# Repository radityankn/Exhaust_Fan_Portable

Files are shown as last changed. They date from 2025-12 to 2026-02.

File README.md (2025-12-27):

| Supported Targets | ESP32 | ESP32-C2 | ESP32-C3 | ESP32-C5 | ESP32-C6 | ESP32-C61 | ESP32-H2 | ESP32-P4 | ESP32-S2 | ESP32-S3 |
| --- | ----- | --- | --- | --- | --- | --- | --- | --- | --- | --- |

# _LEDC Basic Example_

(See the README.md file in the upper level 'examples' directory for more information about examples.)

This example shows how to use the LEDC to generate a PWM signal using the `LOW SPEED` mode.
To use `HIGH SPEED` mode check if the selected SoC supports this mode.

## How to use example

### Hardware Required

* A development board with any Espressif SoC (e.g., ESP32-DevKitC, ESP-WROVER-KIT, etc.)
* A USB cable for power supply and programming

Connect the GPIO to an oscilloscope to see the generated signal:

|ledc channel| GPIO  |
|:---:|:-----:|
| Channel 0  | GPIO5 |

### Configure the project

The example uses fixed PWM frequency of 4 kHz, duty cycle in 50%, and output GPIO pin. To change them, adjust `LEDC_FREQUENCY`, `LEDC_DUTY`, `LEDC_OUTPUT_IO` macros at the top of ledc_basic_example_main.c.

Depending on the selected `LEDC_FREQUENCY`, you will need to change the `LEDC_DUTY_RES`.

To dynamically set the duty and frequency, you can use the following functions:

To set the frequency to 2.5 kHZ i.e:

```c
ledc_set_freq(LEDC_MODE, LEDC_TIMER, 2500);
```

Now set the duty to 100% i.e:

```c
ledc_set_duty(LEDC_MODE, LEDC_CHANNEL, 8192);
ledc_update_duty(LEDC_MODE, LEDC_CHANNEL);
```

To change the duty cycle you need to calculate the duty range according to the duty resolution.

If duty resolution is 13 bits:

Duty range: `0 to (2 ** 13) = 8191` where 0 is 0% and 8192 is 100%.

### Build and Flash

* [ESP-IDF Getting Started Guide](https://idf.espressif.com/)

Build the project and flash it to the board, then run monitor tool to view serial output:

```bash
idf.py -p PORT flash monitor
```

(To exit the serial monitor, type ``Ctrl-]``.)

See the Getting Started Guide for full steps to configure and use ESP-IDF to build projects.

## Example Output

Running this example, you will see the PWM signal with a duty cycle of 50%.

PWM

## Troubleshooting

* Duty Resolution

    * If you get the following error log `ledc: requested frequency and duty resolution can not be achieved, try reducing freq_hz or duty_resolution.` you need to change the `LEDC_DUTY_RES` to a lower resolution and change the range of the duty.

* Programming fail

    * Hardware connection is not correct: run `idf.py -p PORT monitor`, and reboot your board to see if there are any output logs.
    * The baud rate for downloading is too high: lower your baud rate in the `menuconfig` menu, and try again.

For any technical queries, please open an [issue](https://github.com/espressif/esp-idf/issues) on GitHub. We will get back to you soon.

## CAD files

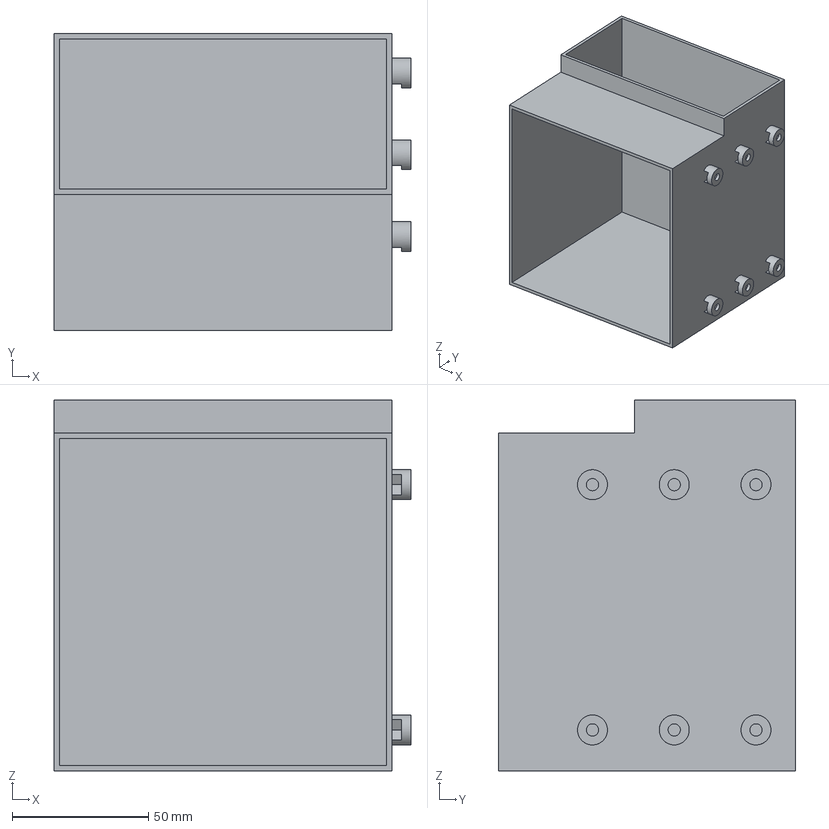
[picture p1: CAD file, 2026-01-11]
exhaust-fan-portable_hardware/Mechanical/3D_Assets/exhaust-fan-portable_assembly-Assemblymain_body.step
131.0 x 109.0 x 136.0 mm

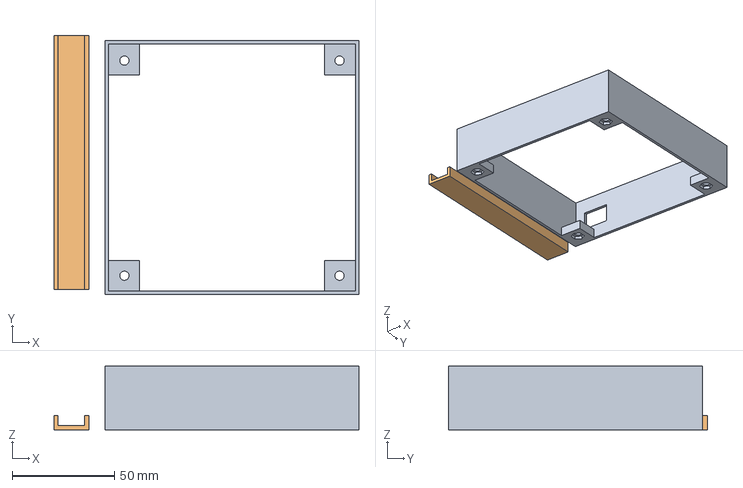
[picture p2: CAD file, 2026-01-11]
exhaust-fan-portable_hardware/Mechanical/Cura_Projects/CE3E3V2_exhaust-fan-portable_assembly-Assemblyfan_attachment.3mf
148.9 x 126.6 x 31.0 mm
exhaust-fan-portable_assembly-Assemblyfan_attachment.stl
exhaust-fan-portable_assembly-Assemblycable_duct.stl

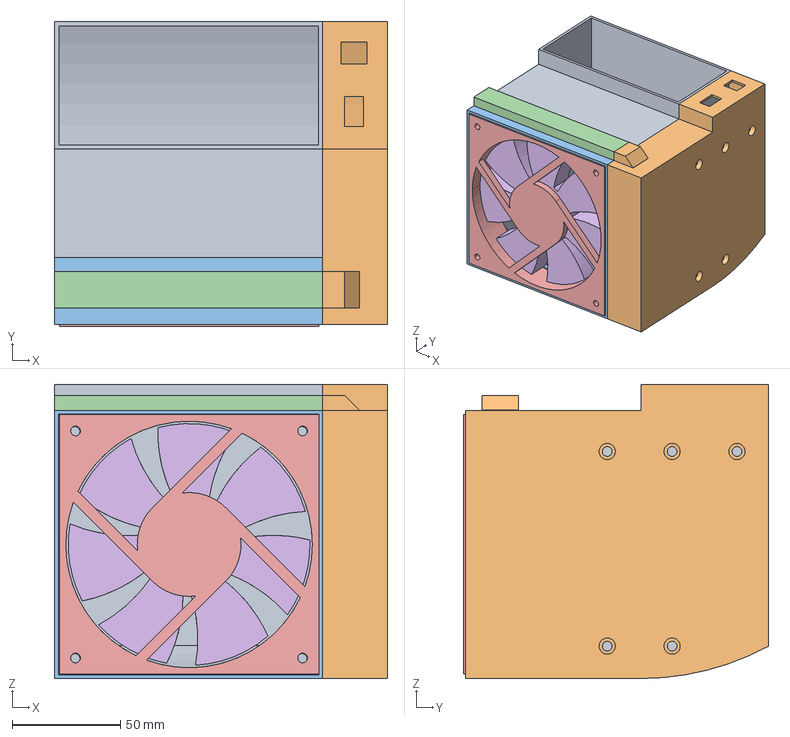
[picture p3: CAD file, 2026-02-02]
exhaust-fan-portable_hardware/Mechanical/exhaust-fan-portable_assembly.FCStd
154.0 x 140.9 x 136.0 mm
main_body
electronic_compartment_lid
fan_attachment
cable_duct
FRAME

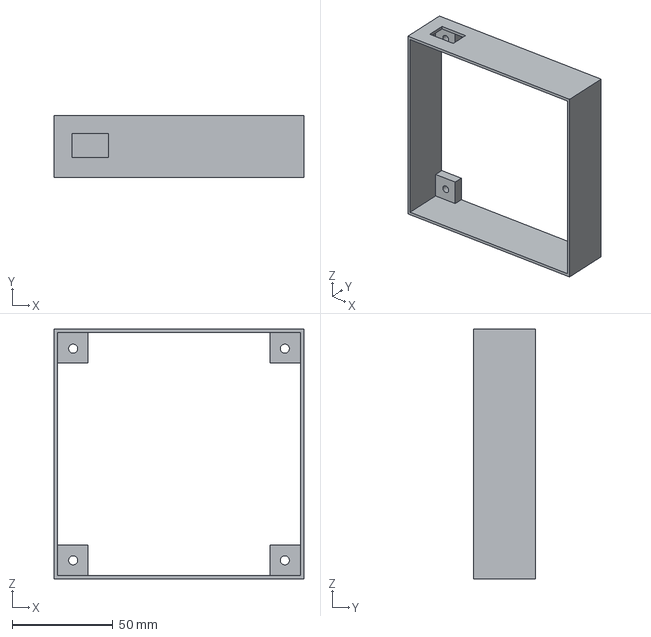
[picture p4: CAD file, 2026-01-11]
exhaust-fan-portable_hardware/Mechanical/3D_Assets/exhaust-fan-portable_assembly-Assemblyfan_attachment.step
124.0 x 31.0 x 124.0 mm

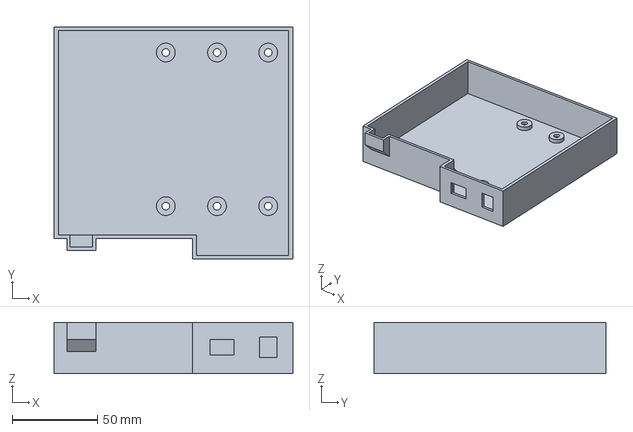
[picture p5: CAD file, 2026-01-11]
exhaust-fan-portable_hardware/Mechanical/Cura_Projects/CE3E3V2_exhaust-fan-portable_assembly-Assemblyelectronic_compartment.3mf
140.0 x 136.0 x 30.0 mm

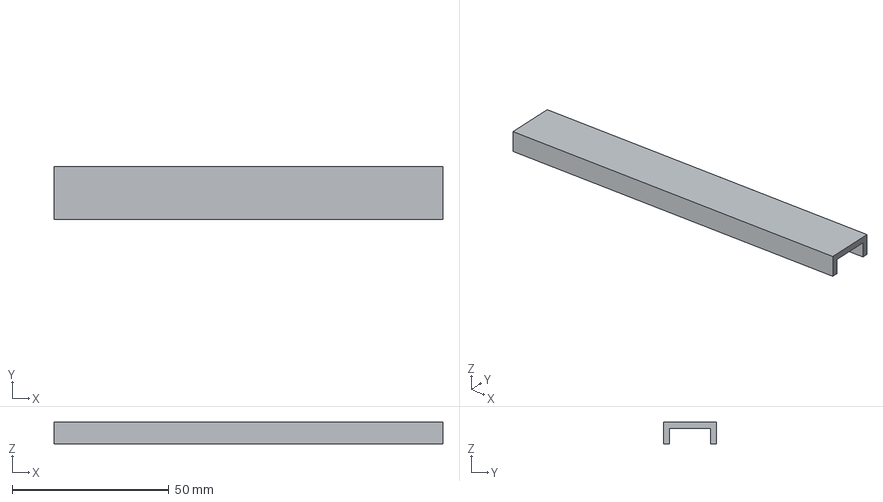
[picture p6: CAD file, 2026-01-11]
exhaust-fan-portable_hardware/Mechanical/3D_Assets/exhaust-fan-portable_assembly-Assemblycable_duct.step
124.0 x 17.0 x 7.00 mm

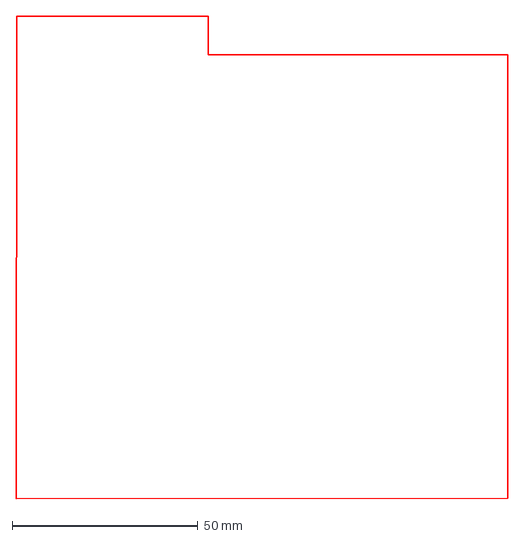
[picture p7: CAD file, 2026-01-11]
exhaust-fan-portable_hardware/Mechanical/2D_Sketches/PCB_drawing.dxf
132.5 x 129.9 mm

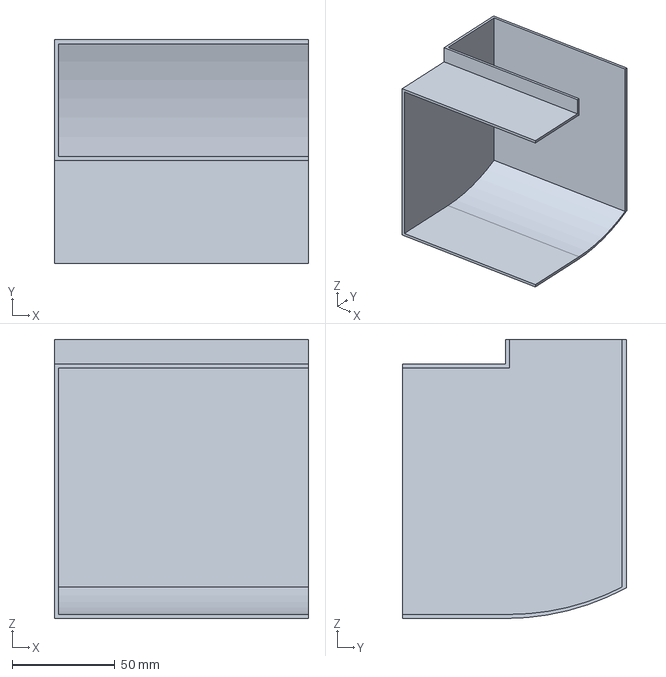
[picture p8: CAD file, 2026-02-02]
exhaust-fan-portable_hardware/Mechanical/exhaust-fan-portable_facegenerator.FCStd
124.0 x 109.0 x 136.0 mm

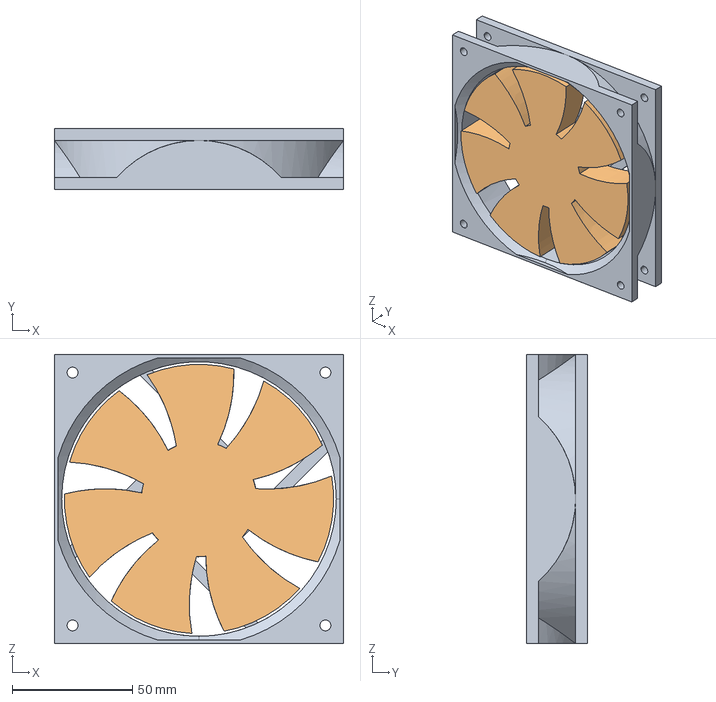
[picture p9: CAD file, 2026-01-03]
exhaust-fan-portable_hardware/Mechanical/3D_Assets/AFB1212SH.stp
120.0 x 25.4 x 120.0 mm
FRAME

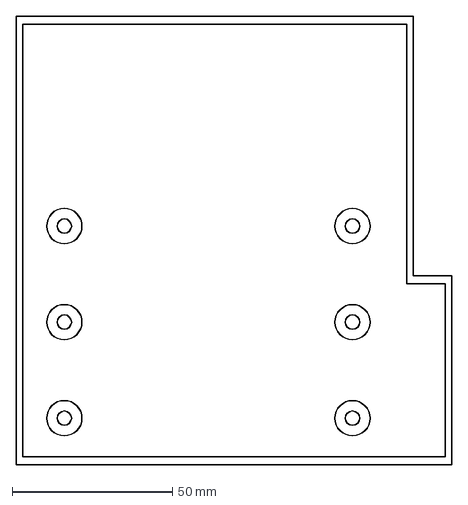
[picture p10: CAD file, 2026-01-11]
exhaust-fan-portable_hardware/Mechanical/2D_Sketches/board_cross_section-screws.dxf
136.0 x 140.0 mm

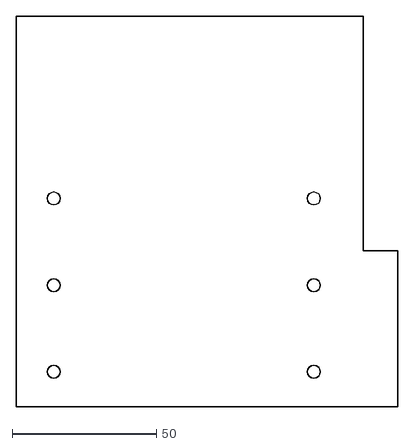
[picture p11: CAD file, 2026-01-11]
exhaust-fan-portable_hardware/Mechanical/2D_Sketches/board_cross_section-screws_2.dxf
132.0 x 135.0

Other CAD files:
exhaust-fan-portable_hardware/Mechanical/3D_Assets/exhaust-fan-portable_assembly-Assemblyelectronic_compartment_lid.step
exhaust-fan-portable_hardware/Mechanical/2D_Sketches/board_cross_section-ports.dxf
exhaust-fan-portable_hardware/Mechanical/3D_Assets/STL/exhaust-fan-portable_assembly-Assemblycable_duct.stl
exhaust-fan-portable_hardware/Mechanical/3D_Assets/STL/exhaust-fan-portable_assembly-Assemblyelectronic_compartment_lid.stl
exhaust-fan-portable_hardware/Mechanical/3D_Assets/STL/exhaust-fan-portable_assembly-Assemblyfan_attachment.stl
exhaust-fan-portable_hardware/Mechanical/3D_Assets/STL/exhaust-fan-portable_assembly-Assemblymain_body.stl

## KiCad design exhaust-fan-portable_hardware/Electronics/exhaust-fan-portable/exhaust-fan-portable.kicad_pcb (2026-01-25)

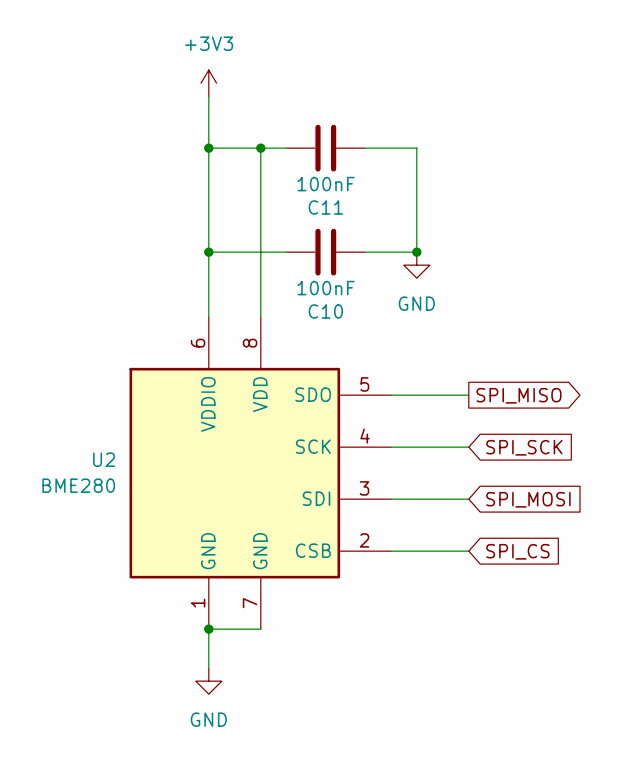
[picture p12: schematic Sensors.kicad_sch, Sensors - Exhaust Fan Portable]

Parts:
C10, C11: 100nF; C_0603_1608Metric_Pad1.08x0.95mm_HandSolder
U2: BME280; Bosch_LGA-8_2.5x2.5mm_P0.65mm_ClockwisePinNumbering

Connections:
+3V3: C10.2, C11.2, U2.6 (VDDIO), U2.8 (VDD); also elsewhere on the board
GND: C10.1, C11.1, U2.1 (GND), U2.7 (GND); also elsewhere on the board
SPI_CS: U2.2 (CSB); also elsewhere on the board
SPI_MISO: U2.5 (SDO); also elsewhere on the board
SPI_MOSI: U2.3 (SDI); also elsewhere on the board
SPI_SCK: U2.4 (SCK); also elsewhere on the board

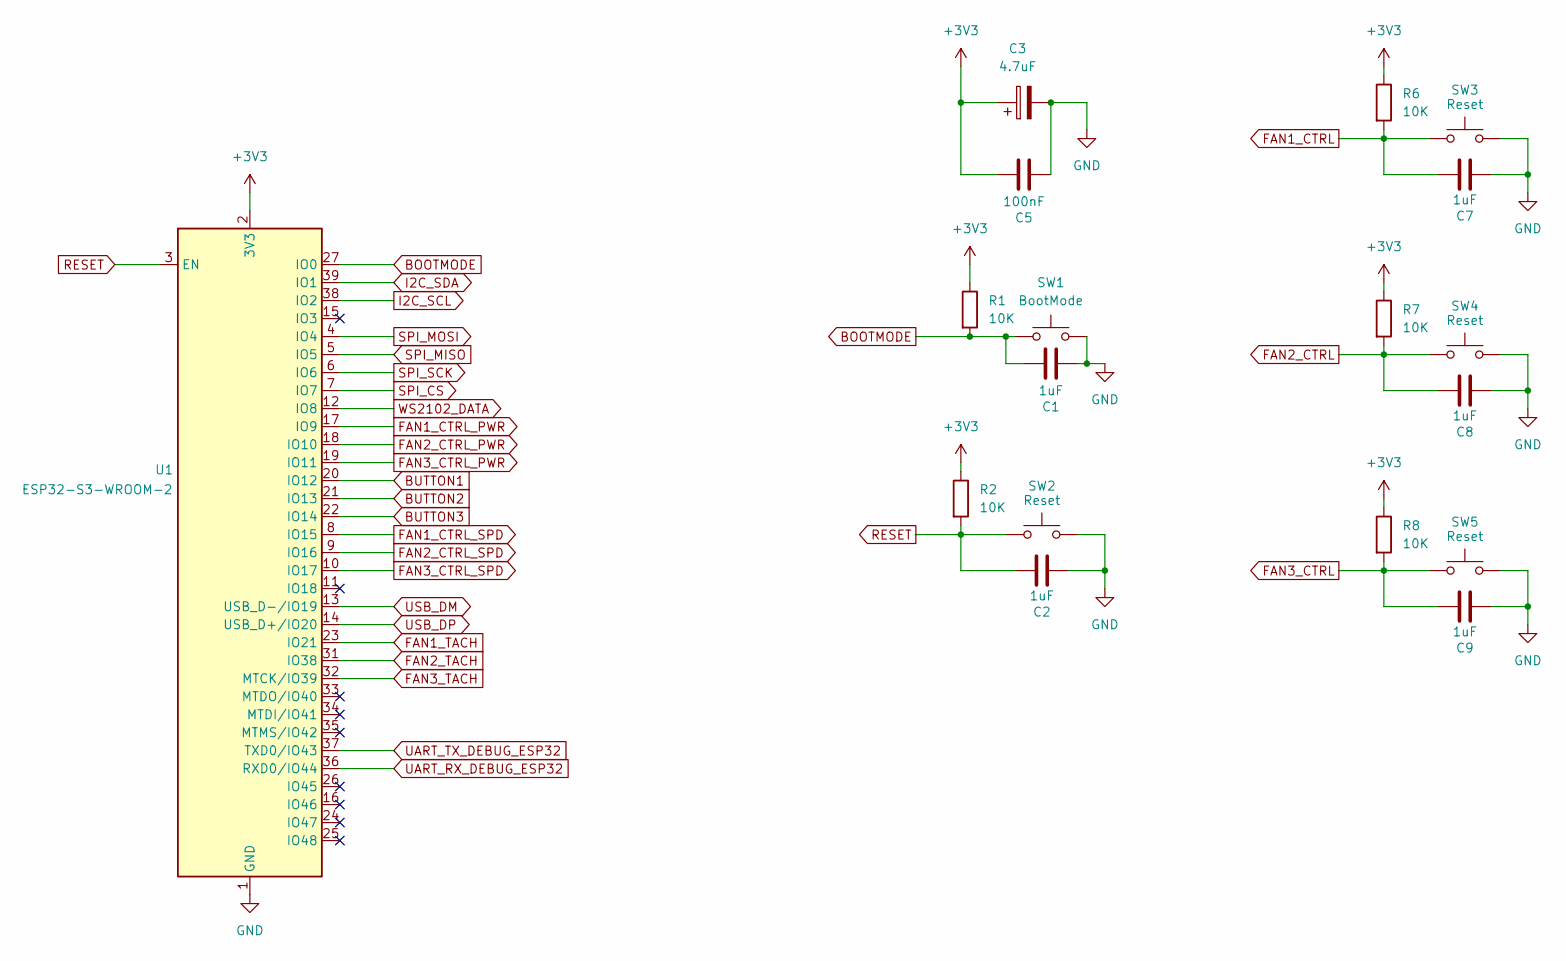
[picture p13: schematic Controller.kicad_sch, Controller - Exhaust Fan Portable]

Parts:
C1, C2, C7, C8, C9: 1uF; C_0805_2012Metric_Pad1.18x1.45mm_HandSolder
C3: 4.7uF; C_1206_3216Metric_Pad1.33x1.80mm_HandSolder
C5: 100nF; C_0603_1608Metric_Pad1.08x0.95mm_HandSolder
R1, R2, R6, R7, R8: 10K; R_0603_1608Metric_Pad0.98x0.95mm_HandSolder
SW1: BootMode; SW_Push_SPST_NO_Alps_SKRK
SW2, SW3, SW4, SW5: Reset; SW_Push_SPST_NO_Alps_SKRK
U1: ESP32-S3-WROOM-2

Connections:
+3V3: C3.1, C5.1, R1.1, R2.1, R6.1, R7.1, R8.1, U1.2 (3V3); also elsewhere on the board
BOOTMODE: C1.1, R1.2, SW1.1, U1.27 (IO0)
BUTTON1: U1.20 (IO12)
BUTTON2: U1.21 (IO13)
BUTTON3: U1.22 (IO14)
FAN1_CTRL: C7.2, R6.2, SW3.2
FAN1_CTRL_PWR: U1.17 (IO9); also elsewhere on the board
FAN1_CTRL_SPD: U1.8 (IO15); also elsewhere on the board
FAN1_TACH: U1.23 (IO21); also elsewhere on the board
FAN2_CTRL: C8.2, R7.2, SW4.2
FAN2_CTRL_PWR: U1.18 (IO10); also elsewhere on the board
FAN2_CTRL_SPD: U1.9 (IO16); also elsewhere on the board
FAN2_TACH: U1.31 (IO38); also elsewhere on the board
FAN3_CTRL: C9.2, R8.2, SW5.2
FAN3_CTRL_PWR: U1.19 (IO11); also elsewhere on the board
FAN3_CTRL_SPD: U1.10 (IO17); also elsewhere on the board
FAN3_TACH: U1.32 (MTCK/IO39); also elsewhere on the board
GND: C1.2, C2.1, C3.2, C5.2, C7.1, C8.1, C9.1, SW1.2, SW2.1, SW3.1, SW4.1, SW5.1, U1.1 (GND), U1.40 (GND), U1.41 (GND); also elsewhere on the board
I2C_SCL: U1.38 (IO2); also elsewhere on the board
I2C_SDA: U1.39 (IO1); also elsewhere on the board
RESET: C2.2, R2.2, SW2.2, U1.3 (EN)
SPI_CS: U1.7 (IO7); also elsewhere on the board
SPI_MISO: U1.5 (IO5); also elsewhere on the board
SPI_MOSI: U1.4 (IO4); also elsewhere on the board
SPI_SCK: U1.6 (IO6); also elsewhere on the board
UART_RX_DEBUG_ESP32: U1.36 (RXD0/IO44); also elsewhere on the board
UART_TX_DEBUG_ESP32: U1.37 (TXD0/IO43); also elsewhere on the board
USB_DM: U1.13 (USB_D-/IO19); also elsewhere on the board
USB_DP: U1.14 (USB_D+/IO20); also elsewhere on the board
WS2102_DATA: U1.12 (IO8); also elsewhere on the board

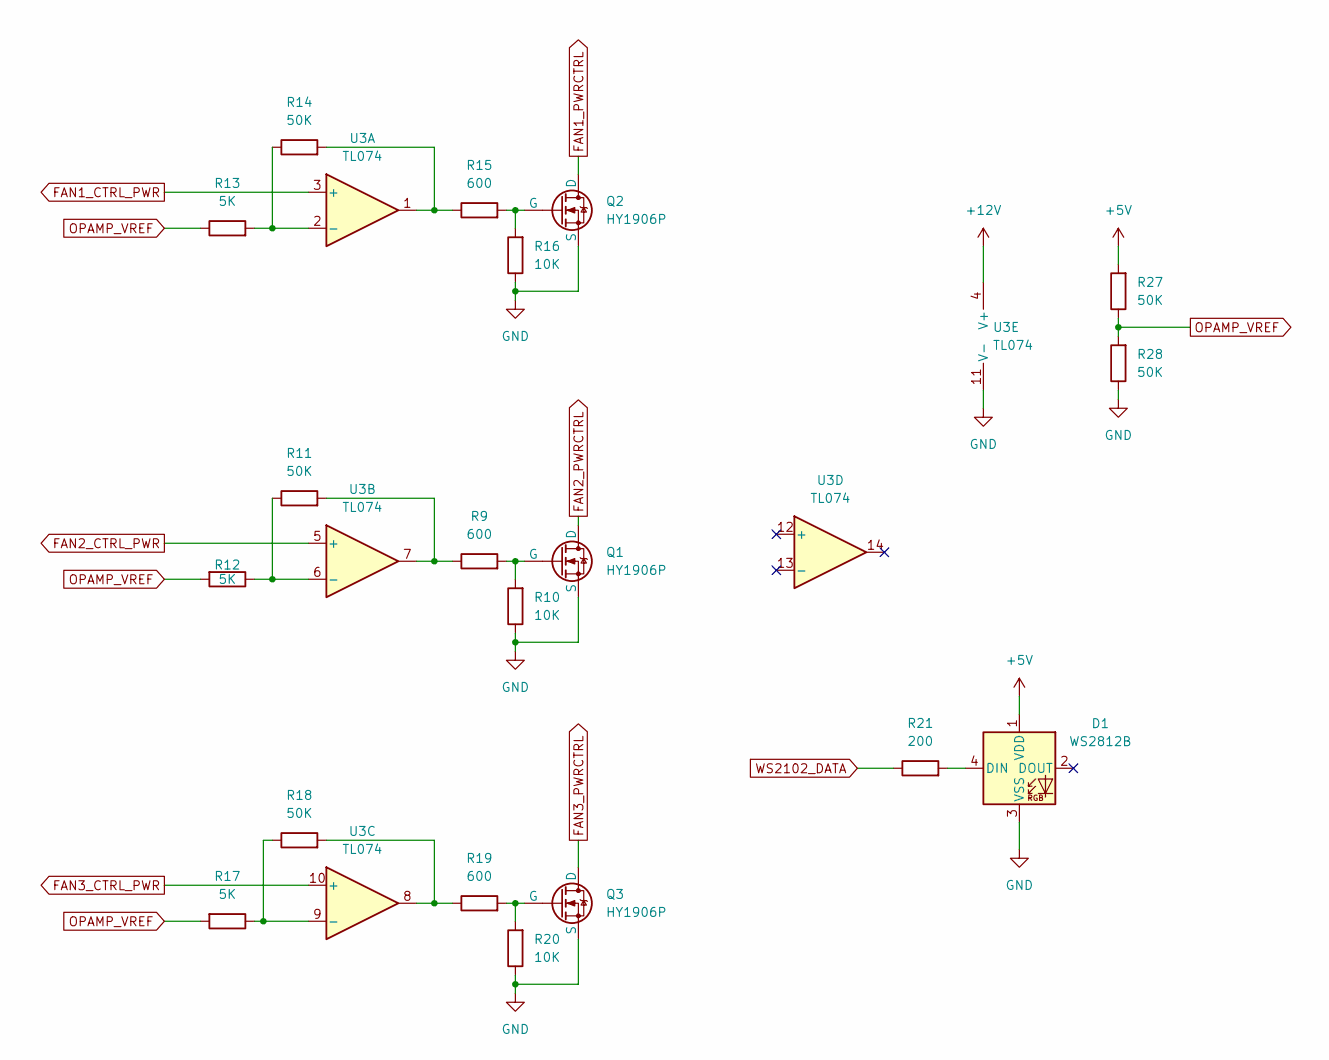
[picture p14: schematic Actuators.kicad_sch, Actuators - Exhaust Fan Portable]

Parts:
D1: WS2812B; LED_WS2812B_PLCC4_5.0x5.0mm_P3.2mm
Q1, Q2, Q3: HY1906P; TO-263-2
R9, R15, R19: 600; R_1206_3216Metric_Pad1.30x1.75mm_HandSolder
R10, R16, R20: 10K; R_0603_1608Metric_Pad0.98x0.95mm_HandSolder
R11, R14, R18, R27, R28: 50K; R_0603_1608Metric_Pad0.98x0.95mm_HandSolder
R12, R13, R17: 5K; R_0603_1608Metric_Pad0.98x0.95mm_HandSolder
R21: 200; R_1206_3216Metric_Pad1.30x1.75mm_HandSolder
U3: TL074; SOIC-14_3.9x8.7mm_P1.27mm

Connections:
+5V: D1.1 (VDD), R27.2; also elsewhere on the board
+12V: U3.4 (V+)
FAN1_CTRL_PWR: U3.3 (+); also elsewhere on the board
FAN1_PWRCTRL: Q2.1 (D); also elsewhere on the board
FAN2_CTRL_PWR: U3.5 (+); also elsewhere on the board
FAN2_PWRCTRL: Q1.1 (D); also elsewhere on the board
FAN3_CTRL_PWR: U3.10 (+); also elsewhere on the board
FAN3_PWRCTRL: Q3.1 (D); also elsewhere on the board
GND: D1.3 (VSS), Q1.3 (S), Q2.3 (S), Q3.3 (S), R10.1, R16.1, R20.1, R28.1, U3.11 (V-); also elsewhere on the board
unnamed: D1.4 (DIN), R21.2
unnamed: Q1.2 (G), R9.2, R10.2
unnamed: Q2.2 (G), R15.2, R16.2
unnamed: Q3.2 (G), R19.2, R20.2
unnamed: R9.1, R11.2, U3.7
unnamed: R14.2, R15.1, U3.1
unnamed: R18.2, R19.1, U3.8
unnamed: R13.2, R14.1, U3.2 (-)
unnamed: R11.1, R12.1, U3.6 (-)
unnamed: R17.1, R18.1, U3.9 (-)
OPAMP_VREF: R12.2, R13.1, R17.2, R27.1, R28.2
WS2102_DATA: R21.1; also elsewhere on the board

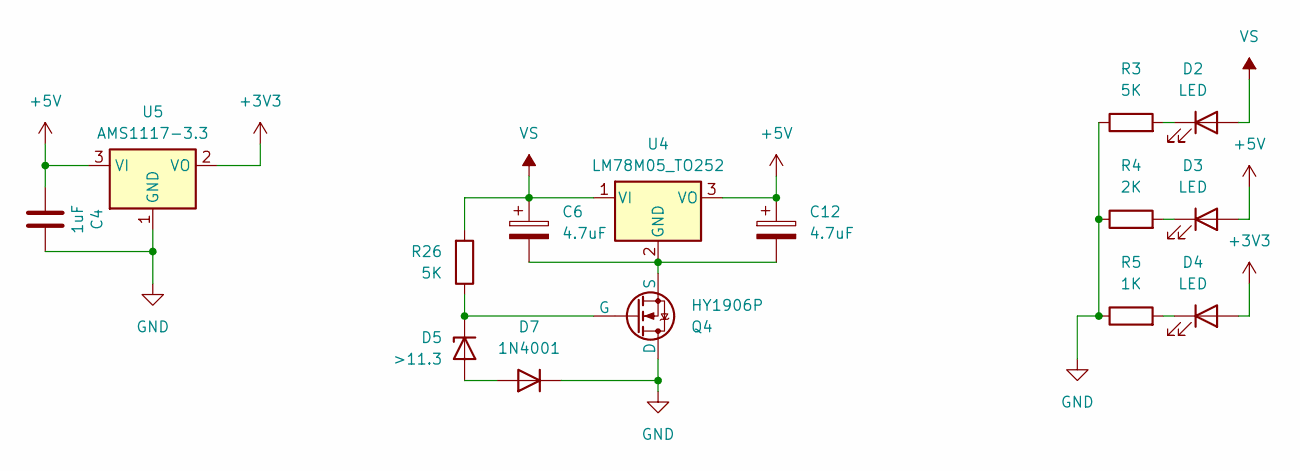
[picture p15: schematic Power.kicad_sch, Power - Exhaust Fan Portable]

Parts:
C4: 1uF; C_0805_2012Metric_Pad1.18x1.45mm_HandSolder
C6, C12: 4.7uF; C_1206_3216Metric_Pad1.33x1.80mm_HandSolder
D2, D3, D4: LED; LED_0603_1608Metric_Pad1.05x0.95mm_HandSolder
D5: >11.3; D_1206_3216Metric_Pad1.42x1.75mm_HandSolder
D7: 1N4001; D_SOD-323_HandSoldering
Q4: HY1906P; TO-263-2
R3, R26: 5K; R_0603_1608Metric_Pad0.98x0.95mm_HandSolder
R4: 2K; R_0603_1608Metric_Pad0.98x0.95mm_HandSolder
R5: 1K; R_0603_1608Metric_Pad0.98x0.95mm_HandSolder
U4: LM78M05_TO252; TO-252-2
U5: AMS1117-3.3; SOT-223-3_TabPin2

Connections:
+3V3: D4.2 (A), U5.2 (VO); also elsewhere on the board
+5V: C4.2, C12.1, D3.2 (A), U4.3 (VO), U5.3 (VI); also elsewhere on the board
GND: C4.1, D7.1 (K), Q4.1 (D), R3.1, R4.1, R5.1, U5.1 (GND); also elsewhere on the board
unnamed: D2.1 (K), R3.2
unnamed: D3.1 (K), R4.2
unnamed: D4.1 (K), R5.2
unnamed: D5.2 (A), D7.2 (A)
unnamed: D5.1 (K), Q4.2 (G), R26.1
unnamed: C6.2, C12.2, Q4.3 (S), U4.2 (GND)
VS: C6.1, D2.2 (A), R26.2, U4.1 (VI); also elsewhere on the board

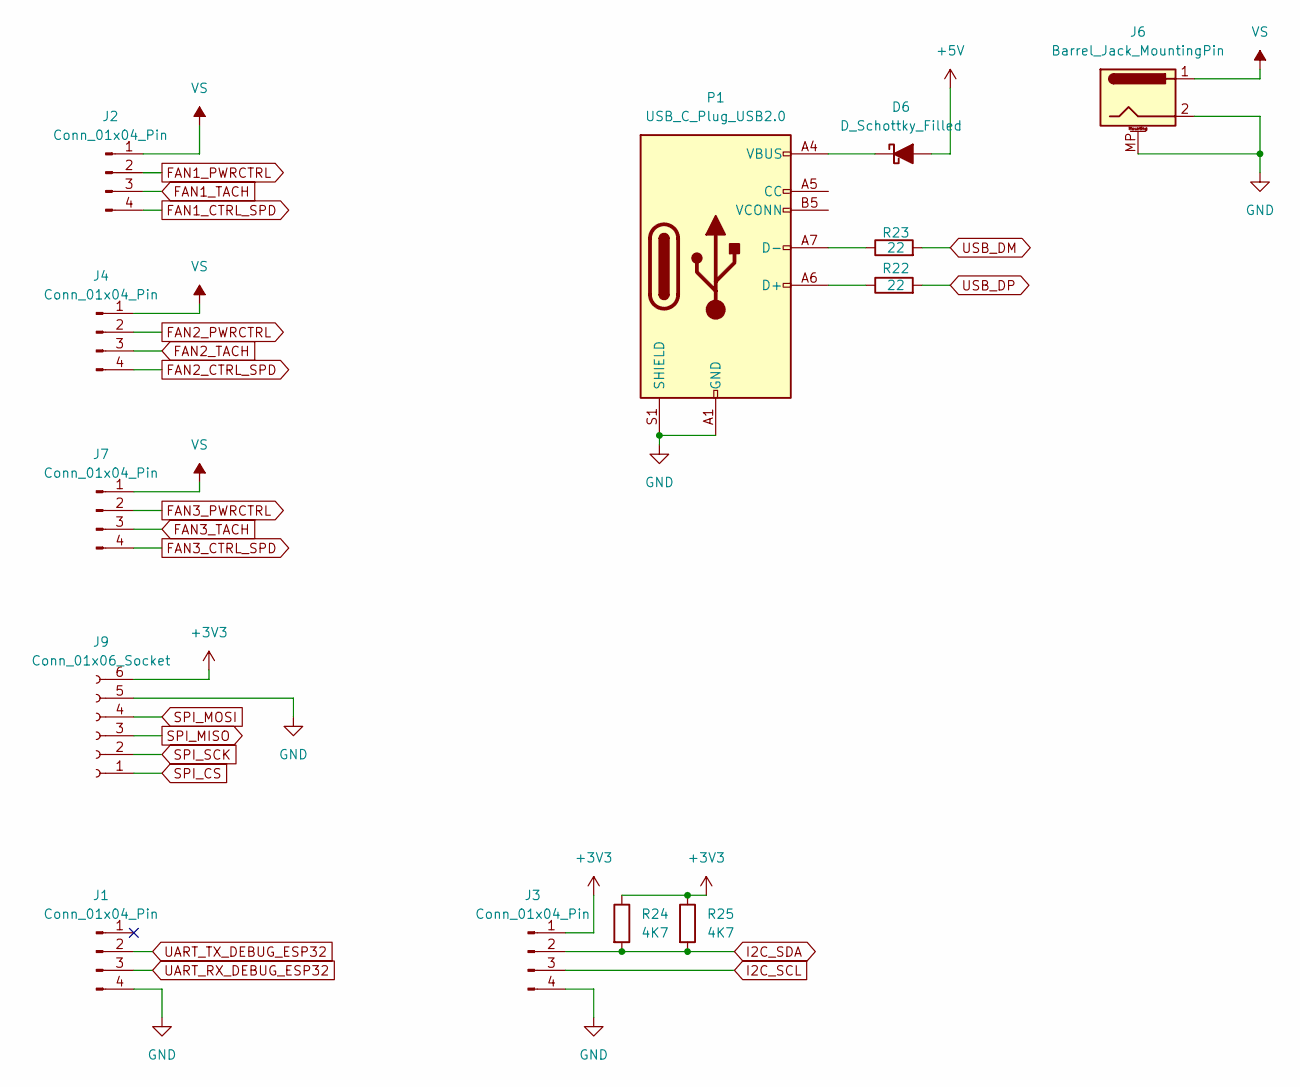
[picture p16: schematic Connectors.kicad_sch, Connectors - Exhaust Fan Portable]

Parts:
D6: D_Schottky_Filled; D_0603_1608Metric_Pad1.05x0.95mm_HandSolder
J1, J2, J3, J4, J7: Conn_01x04_Pin; PinHeader_1x04_P2.54mm_Vertical
J6: Barrel_Jack_MountingPin; BarrelJack_Horizontal
J9: Conn_01x06_Socket; PinSocket_1x06_P2.54mm_Vertical
P1: USB_C_Plug_USB2.0; USB_C_Receptacle_G-Switch_GT-USB-7010ASV
R22, R23: 22; R_0603_1608Metric_Pad0.98x0.95mm_HandSolder
R24, R25: 4K7; R_0603_1608Metric_Pad0.98x0.95mm_HandSolder

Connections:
+3V3: J3.1, J9.6, R24.1, R25.1; also elsewhere on the board
+5V: D6.2 (A); also elsewhere on the board
FAN1_CTRL_SPD: J2.4; also elsewhere on the board
FAN1_PWRCTRL: J2.2; also elsewhere on the board
FAN1_TACH: J2.3; also elsewhere on the board
FAN2_CTRL_SPD: J4.4; also elsewhere on the board
FAN2_PWRCTRL: J4.2; also elsewhere on the board
FAN2_TACH: J4.3; also elsewhere on the board
FAN3_CTRL_SPD: J7.4; also elsewhere on the board
FAN3_PWRCTRL: J7.2; also elsewhere on the board
FAN3_TACH: J7.3; also elsewhere on the board
GND: J1.4, J3.4, J6.2, J6.MP (MountPin), J9.5, P1.A1 (GND), P1.A12 (GND), P1.B1 (GND), P1.B12 (GND), P1.S1 (SHIELD); also elsewhere on the board
I2C_SCL: J3.3; also elsewhere on the board
I2C_SDA: J3.2, R24.2, R25.2; also elsewhere on the board
unnamed: D6.1 (K), P1.A4 (VBUS), P1.A9 (VBUS), P1.B4 (VBUS), P1.B9 (VBUS)
unnamed: P1.A6 (D+), R22.1
unnamed: P1.A7 (D-), R23.1
SPI_CS: J9.1; also elsewhere on the board
SPI_MISO: J9.3; also elsewhere on the board
SPI_MOSI: J9.4; also elsewhere on the board
SPI_SCK: J9.2; also elsewhere on the board
UART_RX_DEBUG_ESP32: J1.3; also elsewhere on the board
UART_TX_DEBUG_ESP32: J1.2; also elsewhere on the board
USB_DM: R23.2; also elsewhere on the board
USB_DP: R22.2; also elsewhere on the board
VS: J2.1, J4.1, J6.1, J7.1; also elsewhere on the board

Board: 2 copper layers, 69 parts (0 on the bottom side), 52 nets, no tracks yet.

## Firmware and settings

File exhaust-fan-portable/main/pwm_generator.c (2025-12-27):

#include <stdio.h>
#include "freertos/FreeRTOS.h"
#include "freertos/task.h"
#include "driver/ledc.h"
#include "esp_err.h"

int led_duty_array[3] = {128, 256, 512};

ledc_timer_config_t timer_config_struct = {
    .speed_mode = LEDC_LOW_SPEED_MODE,
    .duty_resolution = LEDC_TIMER_10_BIT,
    .timer_num = LEDC_TIMER_0,
    .freq_hz = 25000,
    .clk_cfg = LEDC_AUTO_CLK,
};

ledc_channel_config_t channel_config_struct = {
    .gpio_num = 1,
    .channel = LEDC_CHANNEL_0,
    .intr_type = LEDC_INTR_DISABLE,
    .timer_sel = LEDC_TIMER_0,
    .duty = 512,
    .hpoint = 0,
    .sleep_mode = LEDC_SLEEP_MODE_KEEP_ALIVE,
};

void set_pwm_function(ledc_channel_t channel, ledc_timer_t timer, int pin, int value) {
    channel_config_struct.channel = channel;
    channel_config_struct.timer_sel = timer;
    channel_config_struct.gpio_num = pin;
    channel_config_struct.duty = value;

    timer_config_struct.timer_num = timer;

    ESP_ERROR_CHECK(ledc_timer_config(&timer_config_struct));
    ESP_ERROR_CHECK(ledc_channel_config(&channel_config_struct));
}

void app_main(void) {
    set_pwm_function(LEDC_CHANNEL_0, LEDC_TIMER_0, 1, led_duty_array[0]);
    set_pwm_function(LEDC_CHANNEL_1, LEDC_TIMER_0, 2, led_duty_array[1]);
    set_pwm_function(LEDC_CHANNEL_2, LEDC_TIMER_0, 42, led_duty_array[2]);
    //vTaskDelay(3000/portTICK_PERIOD_MS);
    int index_1 = 0;
    int index_2 = 1;
    int index_3 = 2;
    //while (1) {
        //ledc_set_duty_and_update(LEDC_LOW_SPEED_MODE, LEDC_CHANNEL_0, led_duty_array[index_1], 0);
        //ledc_set_duty_and_update(LEDC_LOW_SPEED_MODE, LEDC_CHANNEL_0, led_duty_array[index_2], 0);
        //ledc_set_duty_and_update(LEDC_LOW_SPEED_MODE, LEDC_CHANNEL_0, led_duty_array[index_3], 0);
        //vTaskDelay(3000/portTICK_PERIOD_MS);
        //index_1 = index_2;
        //index_2 = index_3;
        //index_3 = index_1;
    //}
}

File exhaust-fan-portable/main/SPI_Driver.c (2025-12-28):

#include "SPI.h"
#include "SPI_Driver.h"

/*
your SPI object goes here
If there is more than 1 SPI peripheral, you can use the other one
by adding more object
*/

SPIClass spi_object[SPI_PERIPHERAL_NUMBER];

/*
Your SPI setting struct goes here
you can add as many presets as you want, which can be called upon and used when initializing the 
SPI for the sensor or other means
*/

SPISettings spi_object_settings[SPI_PERIPHERAL_NUMBER];

void driver_spi_settings(   spi_handle_t* handler, \
                            spi_number_t peripheral_number, \
                            int clock_rate, int mosi_pin, \
                            int miso_pin, \
                            int clk_pin, \
                            BitOrder data_order, \
                            int data_mode) {

    handler->spi_number = peripheral_number;
    handler->clk_speed = clock_rate;
    handler->mosi_pin = mosi_pin;
    handler->miso_pin = miso_pin;
    handler->clk_pin = clk_pin;
    handler->data_order = data_order;
    handler->data_mode = data_mode;
}

void driver_spi_begin(spi_handle_t *handler, int ss_pin) {
    spi_object[handler->spi_number].setMISO((int)handler->miso_pin);
    spi_object[handler->spi_number].setMOSI((int)handler->mosi_pin);
    spi_object[handler->spi_number].setSCLK((int)handler->clk_pin);
    spi_object[handler->spi_number].setSSEL(ss_pin);

    spi_object_settings[handler->spi_number] = SPISettings(handler->clk_speed, handler->data_order, handler->data_mode);

    spi_object[handler->spi_number].begin();
}

void driver_spi_begin_transaction(spi_handle_t *handler) {
    spi_object[handler->spi_number].beginTransaction(spi_object_settings[handler->spi_number]);
}

void driver_spi_end_transaction(spi_handle_t *handler) {
    spi_object[handler->spi_number].endTransaction();
}

void driver_spi_transfer(spi_handle_t *handler, int &buffer, size_t byte_size) {
    spi_object[handler->spi_number].transfer(buffer, byte_size);
}

int driver_spi_transfer_byte(spi_handle_t *handler, int value) {
    return spi_object[handler->spi_number].transfer(value);
}

void driver_spi_end(spi_handle_t *handler) {
    spi_object[handler->spi_number].end();
}

// Various setup functions
/*
void arduino_spi_set_bit_order(BitOrder data_order) {
    __spi_data_order = data_order;
}

void arduino_spi_set_data_mode(uint8_t data_mode) {
    __spi_data_mode = data_mode;
}
*/

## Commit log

2025-12-27 Initial commit for exhaust fan repo
2025-12-27 1st trial POC FAN
2025-12-28 Added hardware data
    [Actuators.kicad_sch, Connectors.kicad_sch, Controller.kicad_sch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]
2025-12-28 Added driver source codes
2025-12-30 layed out rough schematic and added sensor comparison
    [Actuators.kicad_sch, Connectors.kicad_sch, Controller.kicad_sch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]
2026-01-03 added 3D mechanical assembly (raw sketch)
    [AFB1212SH.stp, exhaust-fan-portable_assembly.FCStd]
2026-01-07 fixed case design
    [Actuators.kicad_sch, Connectors.kicad_sch, Controller.kicad_sch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]
2026-01-11 added mechanical casing v1 along with electronic boards
    [CE3E3V2_exhaust-fan-portable_assembly-Assemblyelectronic_compartment.3mf, CE3E3V2_exhaust-fan-portable_assembly-Assemblyfan_attachment.3mf, PCB_drawing.dxf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]
2026-01-25 updated mechanical information
    [Actuators.kicad_sch, Power.kicad_sch, exhaust-fan-portable.kicad_pcb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]
2026-02-02 completed the mechanical assembly (90%)
    [exhaust-fan-portable_assembly-Assemblyelectronic_compartment_lid.stl, exhaust-fan-portable_assembly-Assemblyfan_attachment.stl, exhaust-fan-portable_assembly.F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]
